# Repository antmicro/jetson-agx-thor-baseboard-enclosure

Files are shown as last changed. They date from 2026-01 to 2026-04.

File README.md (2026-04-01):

# Enclosure for Antmicro baseboard with NVIDIA Jetson AGX Thor

Copyright (c) 2026 [Antmicro](https://www.antmicro.com)

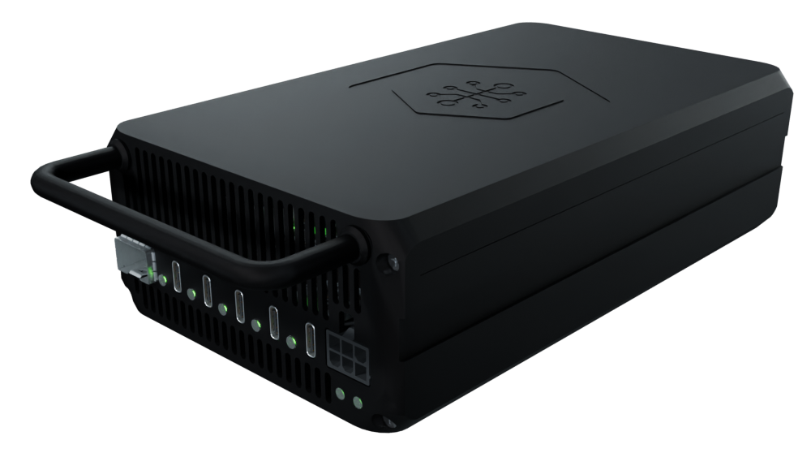
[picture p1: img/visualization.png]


## Overview

This project contains open hardware design files for a CNC-milled enclosure that matches the [Antmicro baseboard](https://github.com/antmicro/jetson-agx-thor-baseboard) for [NVIDIA Jetson AGX Thor (T5000)](https://www.nvidia.com/en-us/autonomous-machines/embedded-systems/jetson-thor/) System on Module.
This black-anodized aluminum enclosure ensures optimal thermal performance when used with DC blower fans.
The enclosure supports pass-through ventilation with air flowing through the enclosure's internal structure.
This allows the use of the enclosure in a stacked assembly (for instance in rack cabinets) or in space-constrained applications.
When installed in a 19" rack cabinet, it is possible to fit up to 8 units in a single row, which uses 2.5U of the vertical space.
The enclosure includes VESA mounting holes and a 1/4" - 20 UNC threaded slot compatible with tripods and other photographic accessories. 

The CNC-milled part files are optimized for compatibility with the popular 3-axis CNC machining process.

You can learn more about the Antmicro Baseboard for NVIDIA Jetson Thor from this [blog article](https://antmicro.com/blog/2026/01/ruggedized-jetson-agx-thor-baseboard-setup).

## Mechanical outline

The mechanical outline along with the overall dimensions is presented in the graphics below.

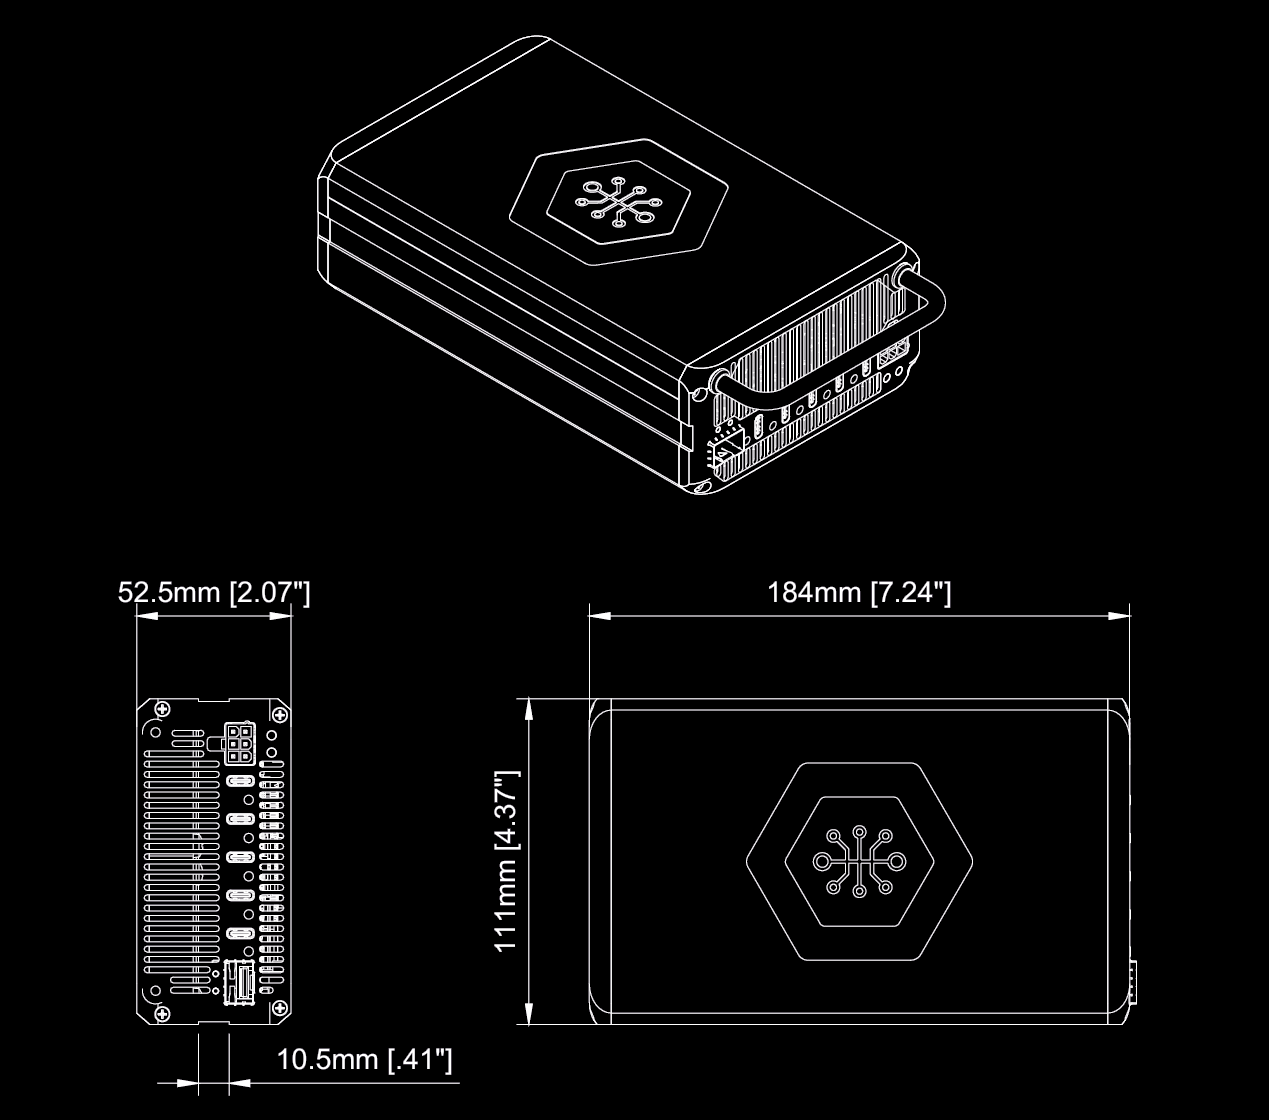
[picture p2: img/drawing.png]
Enclosure drawing


## Thermal performance 

The thermal performance of the enclosure was analyzed with Antmicro [Open source thermal simulation and analysis](https://antmicro.com/blog/2025/03/open-source-thermal-simulation-analysis-and-visualization) methodology expanded with CFD (Computational Fluid Dynamics) capabilities.

### Mechanical bodies and materials used in the simulation
* Aluminum [Enclosure for Antmicro baseboard](antmicro-enclosure-for-jetson-agx-thor.step) with NVIDIA Jetson AGX Thor
* Copper [Heatsink](./step/cnc-milled-som-heatsink-cu.step)
* Aluminum TTP (Thermal Transfer Plate) for NVIDIA Jetson AGX Thor SoM
* [3D printed shroud](./step/3d-printed-fan-shroud-pc.step) which directs the air flow inside the enclosure
* Simplified model of the Antmicro Baseboard for NVIDIA Jetson AGX Thor
* 2x blower fan - Sunon EF50151BX-1B000-A99

### Simulation constraints
* Ambient temperature of 23°C (73.4°F)
* 130W heat source applied to the NVIDIA Jetson AGX Thor SoM TTP facing the copper heatsink
* Source of the air flow rated with respect to the performance curve derived from the fan datasheet

### Simulation results


The simulated peak temperature was 74°C (165.2°F) obtained at a spot between the NVIDIA Jetson AGX Thor SoM TTP and the copper heatsink.

The simulation confirms that the designed thermal solution meets the thermal management requirements specified in the [NVIDIA Jetson Thor Series Modules Thermal Design Guide](https://developer.nvidia.com/downloads/assets/embedded/secure/jetson/thor/docs/jetson_thor_thermal_dg_tdg12271001.pdf).

## Project structure

The project files are stored in the following directories:

* ``step`` - contains STEP files of the 3d-printable, CNC-manufacturable parts and additional (i.e. off-the-shelf) components and fastening parts needed to assemble the enclosure
* ``blend`` - contains .blend files derived from the STEP files
* ``drawings`` - contains mechanical drawings of the CNC-manufacturable parts in PDF format
* ``img`` - contains graphics for this README
* ``bom`` - contains the bill of materials

## Licensing

This project is published under the [Apache-2.0](LICENSE) license.

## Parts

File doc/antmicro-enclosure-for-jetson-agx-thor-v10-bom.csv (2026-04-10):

part_name | part_number | description | quantity | step
3d_printed_backflow_baffle_pc | P-JAT-BB-PC-N | Baffle that isolates intake and exhaust airflow to prevent backflow into fans | 1 | 3d-printed-backflow-baffle-pc.step
3d_printed_fan_shroud_pc | P-JAT-FS-PC-N | Directs internal airflow to improve thermal management efficiency | 1 | 3d-printed-fan-shroud-pc.step
Countersunk Head Screw DIN EN ISO 7046-2 - M2.5 x 10 - H Steel 4.6 Plain v1 | DIN EN ISO 7046-2 - M2.5x10 - H Steel 4.6 Plain | Countersunk Head Screw DIN EN ISO 7046-2 - M2.5 x 10 - H | 7 | countersunk-head-screw-din-en-iso-7046-2-m2-5-x-10-h-steel-4-6-plain-v1.step
Countersunk Head Screw DIN EN ISO 7046-2 - M2.5 x 8 - H Steel 4.6 Plain v1 | DIN EN ISO 7046-2 - M2.5x8 - H Steel 4.6 Plain | Countersunk Head Screw DIN EN ISO 7046-2 - M2.5 x 8 - H | 8 | countersunk-head-screw-din-en-iso-7046-2-m2-5-x-8-h-steel-4-6-plain-v1.step
Raised Cheese Head Screw DIN 7985 - M4 x 18 - H Steel 4.6 Plain v1 | DIN 7985 - M4x18-H H Steel 4.6 Plain | Raised Cheese Head Screw DIN 7985 - M4 x 18 - H | 4 | raised-cheese-head-screw-din-7985-m4-x-18-h-steel-4-6-plain-v1.step
Raised Cheese Head Screw DIN 7985 - M4 x 8 - H Steel 4.6 Plain v1 | DIN 7985 - M4x8-H H Steel 4.6 Plain | Raised Cheese Head Screw DIN 7985 - M4 x 8 - H | 2 | raised-cheese-head-screw-din-7985-m4-x-8-h-steel-4-6-plain-v1.step
cnc_milled_back_panel_al | C-JAT-BP-AL-A | Rear panel with vertical ribs for air exhaust | 1 | cnc-milled-back-panel-al.step
cnc_milled_bottom_shell_al | C-JAT-BS-AL-A | Main body with internal PCB mounting points and external enclosure mounting features | 1 | cnc-milled-bottom-shell-al.step
cnc_milled_front_panel_al | C-JAT-FP-AL-A | Front panel serving as primary air inlet and interface surface | 1 | cnc-milled-front-panel-al.step
cnc_milled_som_heatsink_cu | C-JAT-SH-CU-N | Facilitates heat dissipation from the module to maintain optimal operating temperatures - use high purity copper for best thermal performance | 1 | cnc-milled-som-heatsink-cu.step
cnc_milled_top_cover_al | C-JAT-TC-AL-A | Top lid providing structural closure and mounting points for fan blowers | 1 | cnc-milled-top-cover-al.step
cots_Elesa_Ganter_GN_425-8-88-BT v4 | GN 425-6-88-BT | Grip for carrying the enclosure and enabling stacking and clustering | 1 | cots-elesa-ganter-gn-425-8-88-bt-v4.step
cots_Mentor_1282.1200 v6 | 1282.1200 | Transparent plastic light pipe panel-mounted | 5 | cots-mentor-1282-1200-v6.step
cots_Sunon_EF50151BX-1B000-A99 v7 | EF50151BX-1B000-A99 | 12V DC blower fan for enclosure airflow - 50x50x15mm | 2 | cots-sunon-ef50151bx-1b000-a99-v7.step

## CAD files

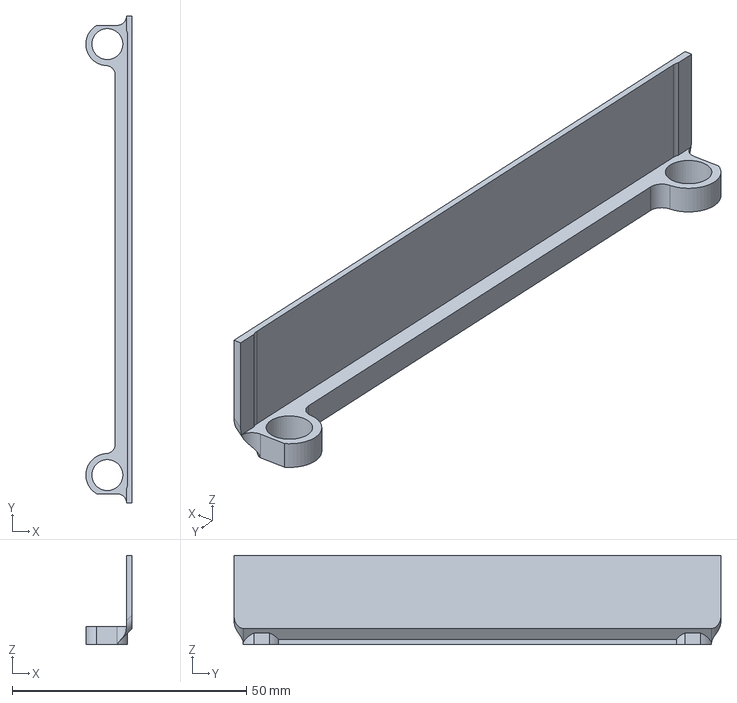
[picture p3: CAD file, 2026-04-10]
step/3d-printed-backflow-baffle-pc.step
9.88 x 104.0 x 19.0 mm

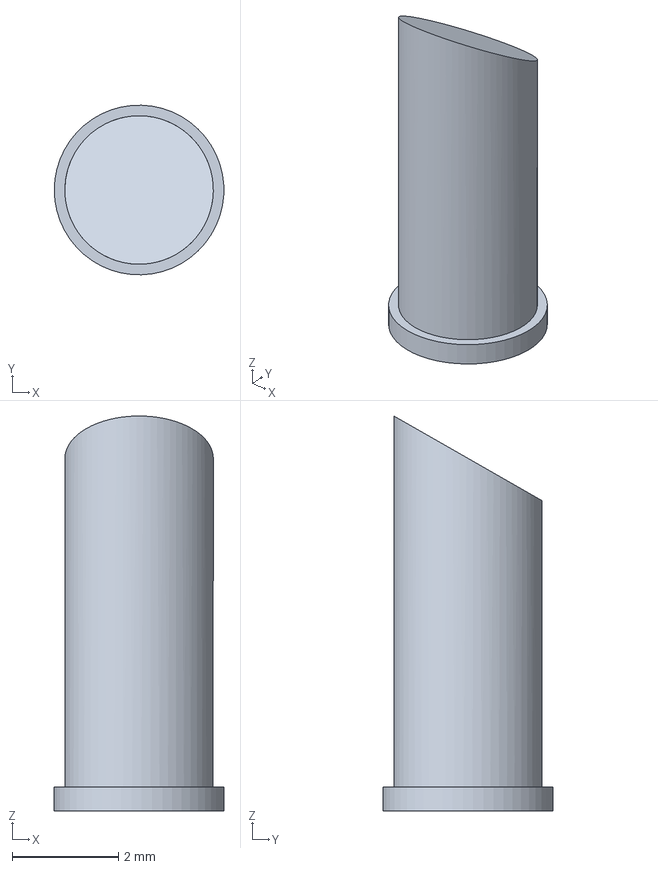
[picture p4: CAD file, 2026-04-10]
step/cots-mentor-1282-1200-v6.step
3.20 x 3.20 x 7.45 mm

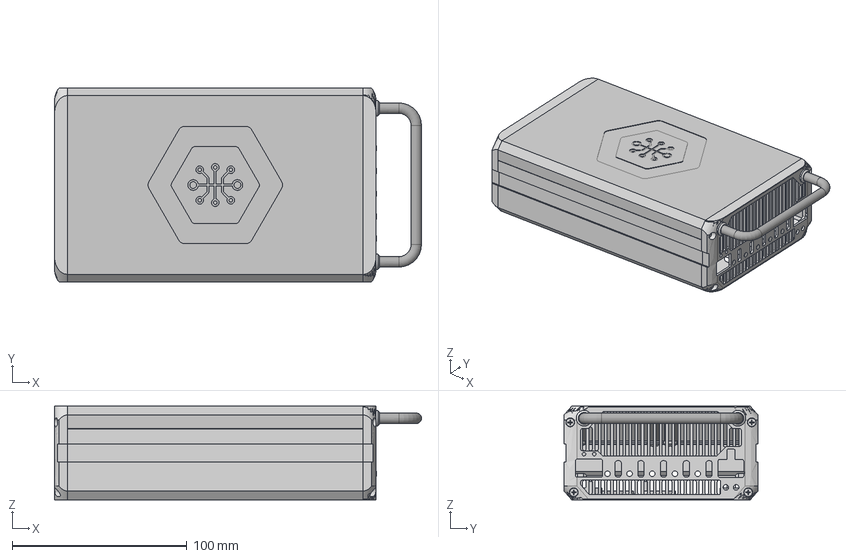
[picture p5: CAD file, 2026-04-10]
step/antmicro-enclosure-for-jetson-agx-thor.step
210.0 x 111.0 x 53.5 mm
C-JAT-TC-AL-A
C-JAT-FP-AL-A
C-JAT-BS-AL-A
DIN 7985 - M4x8-H H Steel 4.6 Plain x 2
DIN EN ISO 7046-2 - M2.5x8 - H Steel 4.6 Plain x 8
DIN EN ISO 7046-2 - M2.5x10 - H Steel 4.6 Plain x 7
DIN 7985 - M4x18-H H Steel 4.6 Plain x 4
C-JAT-SH-CU-N
C-JAT-BP-AL-A
GN 425-6-88-BT
EF50151BX-1B000-A99 x 2
P-JAT-FS-PC-N
P-JAT-BB-PC-N

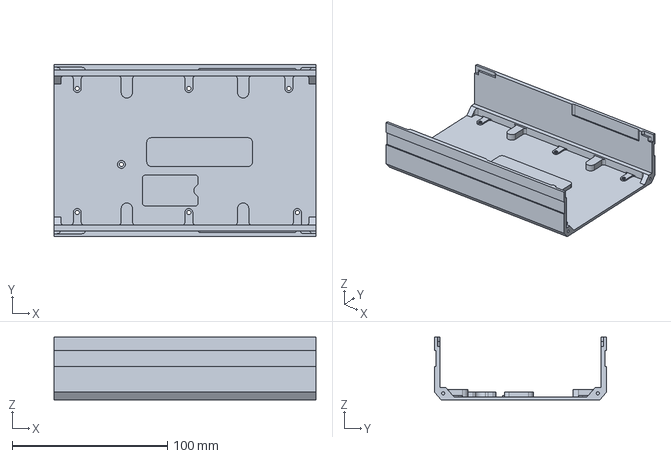
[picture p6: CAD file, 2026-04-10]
step/cnc-milled-bottom-shell-al.step
169.0 x 111.0 x 40.5 mm

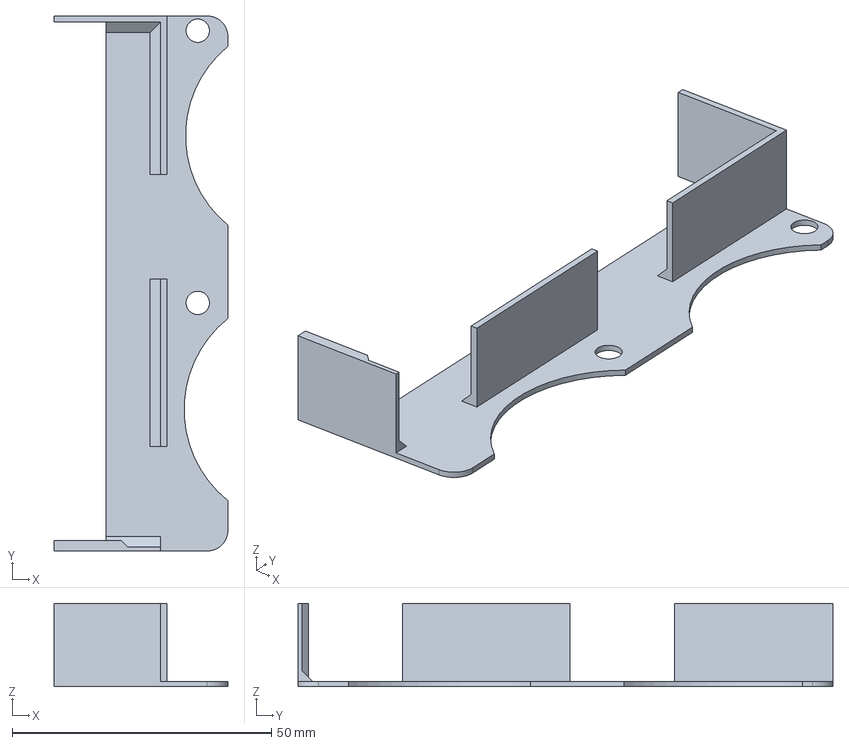
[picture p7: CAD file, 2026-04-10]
step/3d-printed-fan-shroud-pc.step
33.6 x 103.2 x 16.0 mm

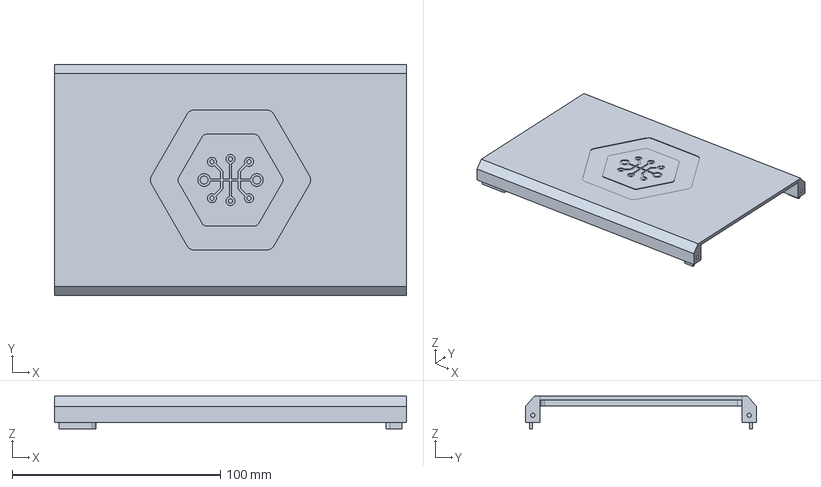
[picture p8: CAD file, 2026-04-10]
step/cnc-milled-top-cover-al.step
169.0 x 111.0 x 15.8 mm

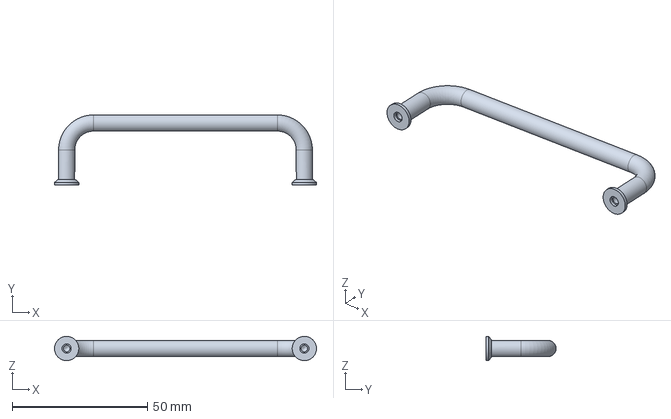
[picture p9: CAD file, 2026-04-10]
step/cots-elesa-ganter-gn-425-8-88-bt-v4.step
97.0 x 26.0 x 8.99 mm

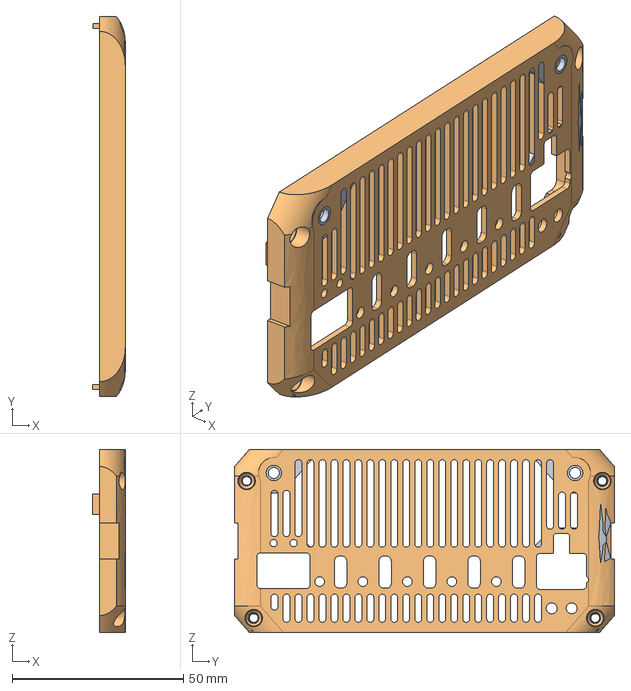
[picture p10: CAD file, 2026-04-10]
step/cnc-milled-front-panel-al.step
9.50 x 111.0 x 53.5 mm
C-JAT-FP-AL-A x 2

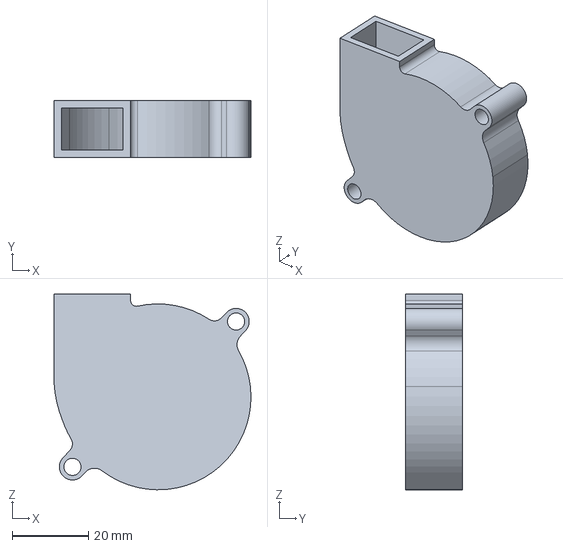
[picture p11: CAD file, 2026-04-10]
step/cots-sunon-ef50151bx-1b000-a99-v7.step
51.8 x 15.0 x 51.4 mm

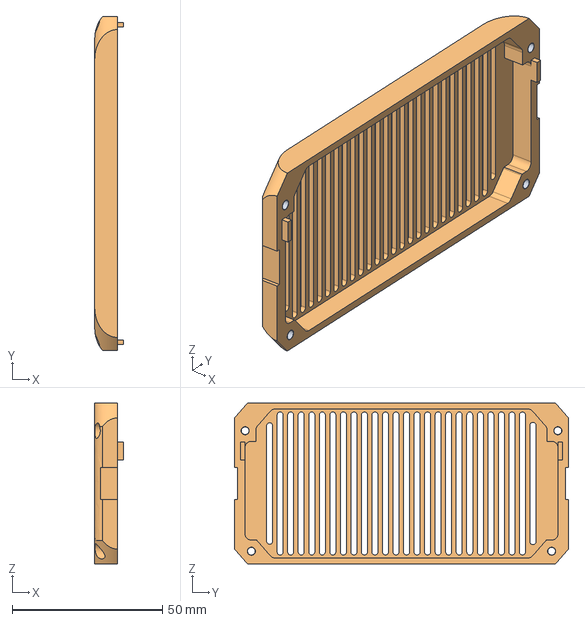
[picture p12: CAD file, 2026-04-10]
step/cnc-milled-back-panel-al.step
9.50 x 111.0 x 53.5 mm
C-JAT-BP-AL-A x 2

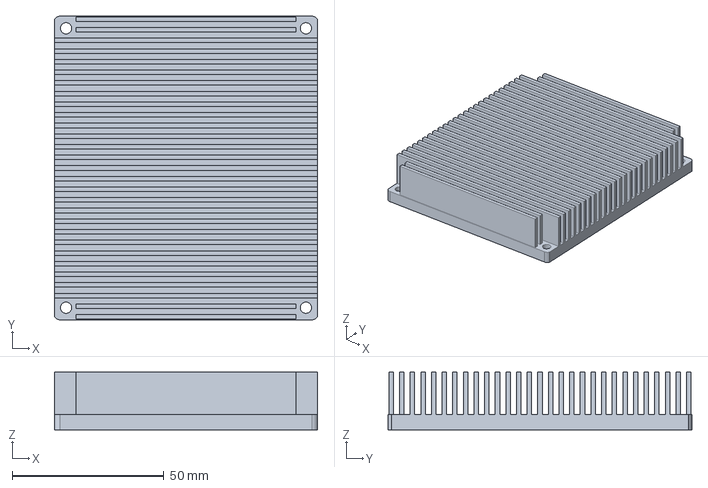
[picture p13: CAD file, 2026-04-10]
step/cnc-milled-som-heatsink-cu.step
86.6 x 100.0 x 19.0 mm

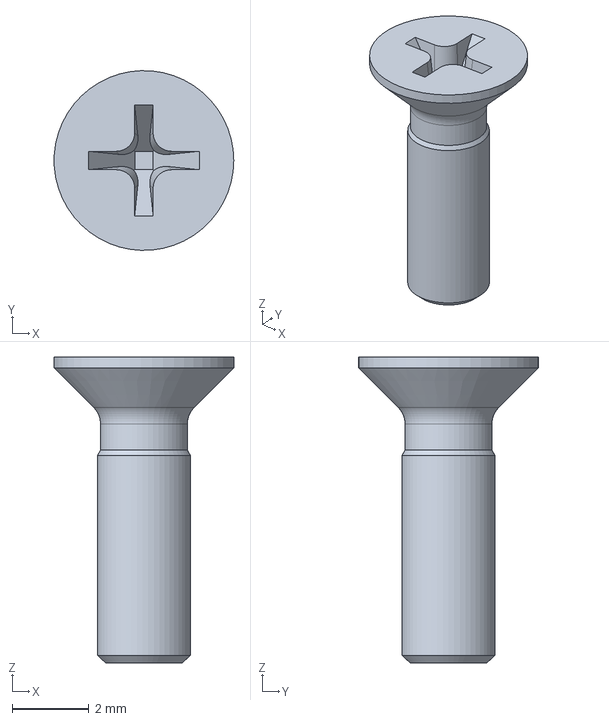
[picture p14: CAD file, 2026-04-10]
step/countersunk-head-screw-din-en-iso-7046-2-m2-5-x-8-h-steel-4-6-plain-v1.step
4.70 x 4.70 x 8.00 mm

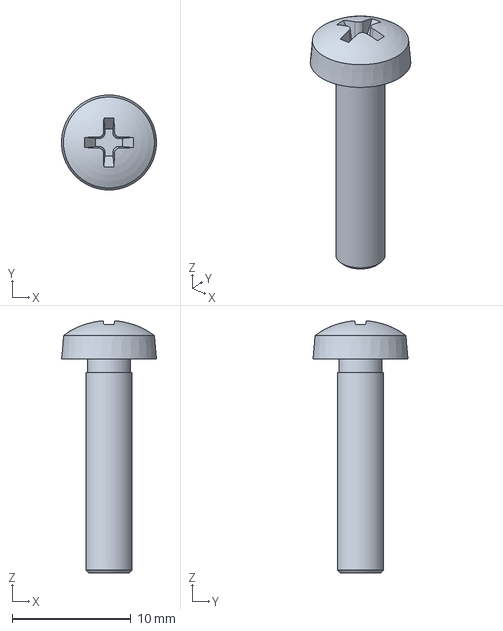
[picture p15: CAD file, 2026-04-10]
step/raised-cheese-head-screw-din-7985-m4-x-18-h-steel-4-6-plain-v1.step
7.99 x 8.00 x 21.2 mm

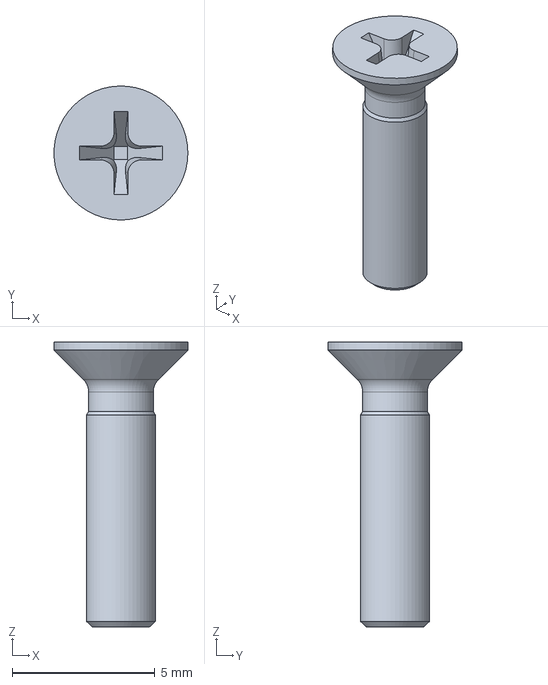
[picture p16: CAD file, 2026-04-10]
step/countersunk-head-screw-din-en-iso-7046-2-m2-5-x-10-h-steel-4-6-plain-v1.step
4.70 x 4.70 x 10.0 mm

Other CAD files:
step/raised-cheese-head-screw-din-7985-m4-x-8-h-steel-4-6-plain-v1.step
step/cots-sunon-ef50151bx-1b000-a99.step
step/cots-mentor-1282-1200.step
step/raised-cheese-head-screw-din-7985-m4-x-18-h-steel-4-6-plain.step
blend/3d-printed-fan-shroud-pc.blend
blend/cnc-milled-back-panel-al.blend
blend/cnc-milled-bottom-shell-al.blend
blend/cnc-milled-front-panel.blend
blend/cnc-milled-som-heatsink-cu.blend
blend/cnc-milled-top-cover-al.blend
blend/cots-mentor-1282-1200.blend
blend/cots-sunon-ef50151bx-1b000-a99.blend
blend/cots_elesa_ganter_gn_425-8-88-bt.blend
step/countersunk-head-screw-din-en-iso-7046-2-m2-5-x-10-h-steel-4-6-plain.step
step/countersunk-head-screw-din-en-iso-7046-2-m2-5-x-8-h-steel-4-6-plain.step
step/raised-cheese-head-screw-din-7985-m4-x-8-h-steel-4-6-plain.step

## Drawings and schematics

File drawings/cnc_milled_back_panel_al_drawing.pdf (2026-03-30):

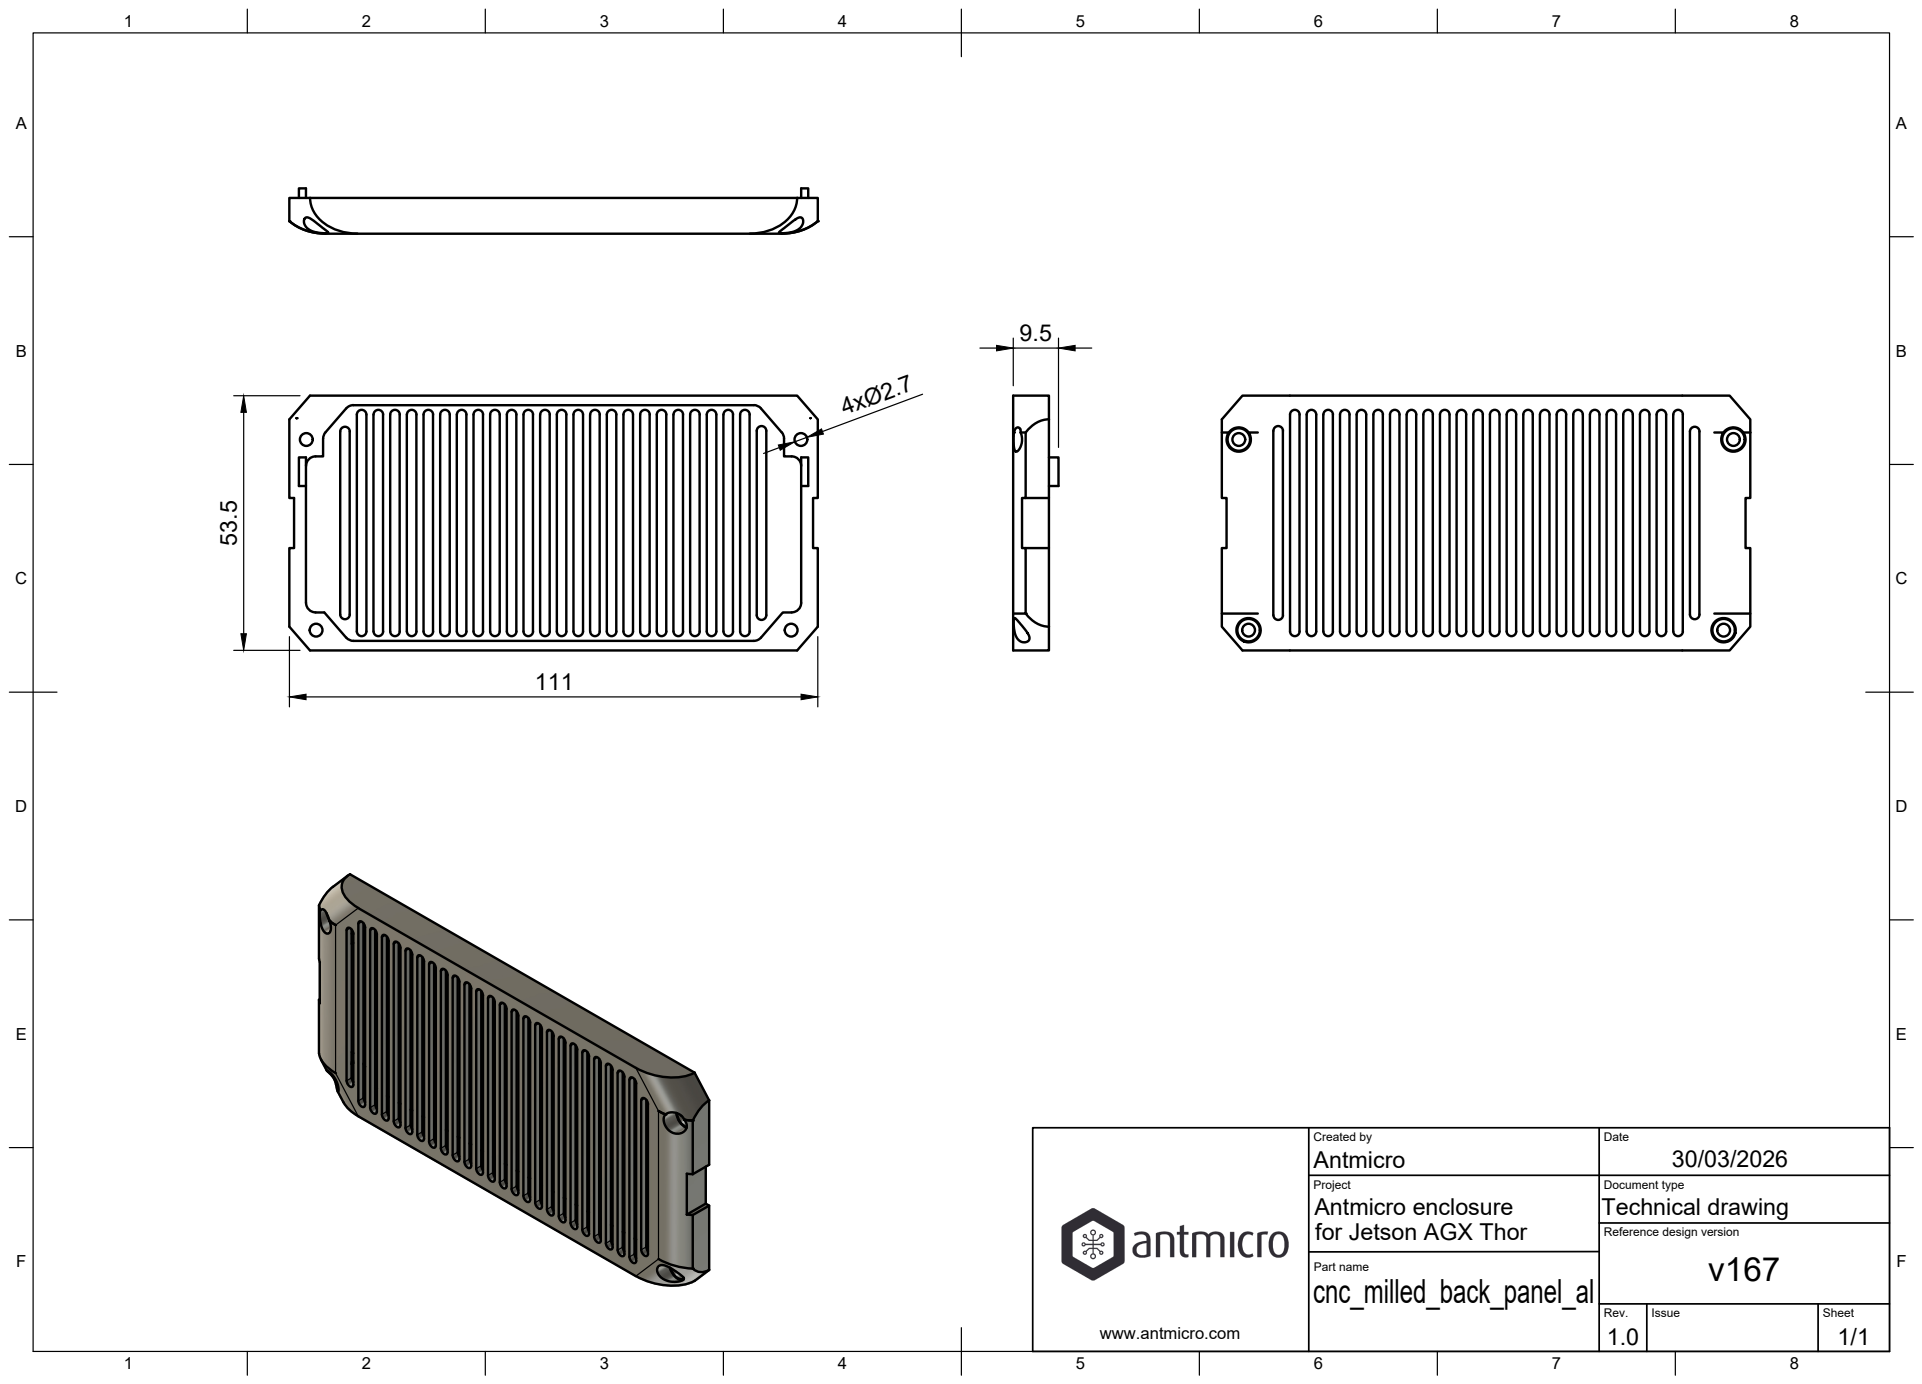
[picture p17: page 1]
Part name

Created by Antmicro | Date 30/03/2026

Project Antmicro enclosure for Jetson AGX Thor | Document type Technical drawing

Reference design version

www.antmicro.com

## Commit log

2025-12-31 Add initial step model of baseboard enclosure
    [jetson-agx-thor-baseboard_enclosure.step]
2025-12-31 Separate enslocure parts
    [jetson-agx-thor-baseboard-enclosure-bottom.step, jetson-agx-thor-baseboard-enclosure-grid-holes.step, jetson-agx-thor-baseboard-enclosure-handle.step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]
2025-12-31 Add colored models of enclosure
    [jetson-agx-thor-baseboard-enclosure-bottom.blend, jetson-agx-thor-baseboard-enclosure-grid-holes.blend, jetson-agx-thor-baseboard-enclosure-handle.blend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]
2025-12-31 fixup! Add initial step model of baseboard enclosure
    [jetson-agx-thor-baseboard_enclosure.step]
2025-12-31 Move models to assembly dir
    [jetson-agx-thor-baseboard-enclosure-bottom.blend, jetson-agx-thor-baseboard-enclosure-bottom.step, jetson-agx-thor-baseboard-enclosure-grid-holes.blend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]
2025-12-31 Add assembly CI, yaml and assembly model
    [assembly.blend]
2025-12-31 Add explode animation
    [assembly.blend]
2026-01-05 Correct color of grid
    [jetson-agx-thor-baseboard-enclosure-grid-holes.blend]
2026-01-23 [#90037] Update enclosure
    [1282.1200.blend, EF50151BX-1B000-A99.blend, GN_425-6-88-BT.blend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]
2026-01-23 Set logo to black
    [Thor_Top.blend]
2026-01-23 Add shroud model
    [shroud_EF50151BX-1B00U-A99.blend]
2026-01-29 [#90422] Add readme
    [Cabinet_U-Handle_Steel_GN_425-6-88-BT.step, EF50151BX-1B000-A99.step, Thor_Back.step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]
2026-03-30 [#94115] Update file names
    [3d-printed-fan-shroud-pc.step, EF50151BX-1B000-A99.step, Thor_Back.step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]
2026-03-30 [#94115] Update part names in BOM
    [jetson-agx-thor-baseboard_enclosure_bom.csv]
2026-03-31 [#94115] Update file attributes
    [antmicro_enclosure_for_jetson_agx_thor.step, cots_Elesa_Ganter_GN_425-8-88-BT.step]
2026-03-31 [#94115] Unify step file naming
    [antmicro-enclosure-for-jetson-agx-thor.step, cots-mentor-1282-1200.step, cots-sunon-ef50151bx-1b000-a99-sunon.step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]
2026-03-31 [#94115] Update blend file names
    [3d-printed-fan-shroud-pc.blend, cnc-milled-back-panel-al.blend, cnc-milled-bottom-shell-al.blend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]
2026-04-03 [#94115] Update part description
    [3d-printed-fan-shroud-pc.step, antmicro-baseboard-for-jetson-agx-thor.step, antmicro-enclosure-for-jetson-agx-thor-v5-bom.csv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]
2026-04-10 [#94804] Add backflow baffle
    [3d-printed-backflow-baffle-pc.step, 3d-printed-fan-shroud-pc.step, antmicro-baseboard-for-jetson-agx-thor.step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]
2026-04-10 [#94804] Update html bom
